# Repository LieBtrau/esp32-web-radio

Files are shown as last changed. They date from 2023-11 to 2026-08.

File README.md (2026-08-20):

# Description

<td>
<table>
  <tr>
    <td>
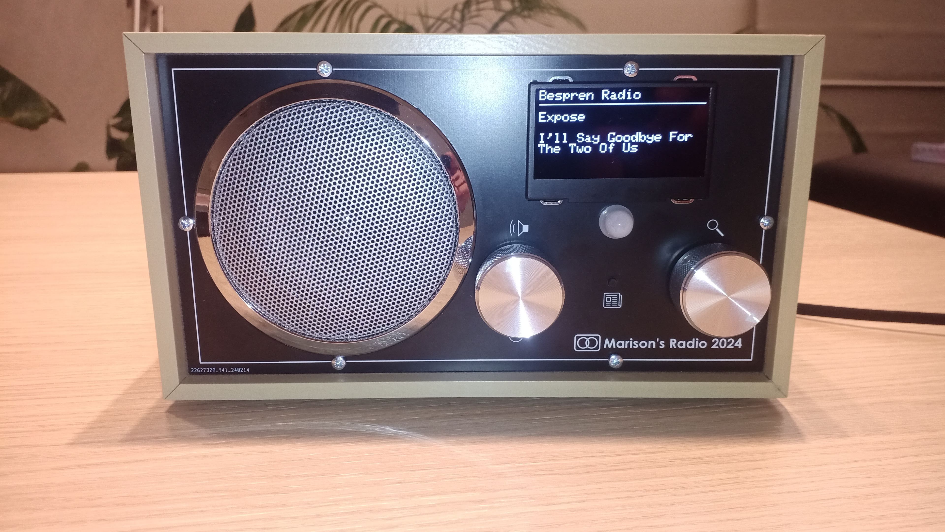
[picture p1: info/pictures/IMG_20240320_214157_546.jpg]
      
    </td>
    <td>
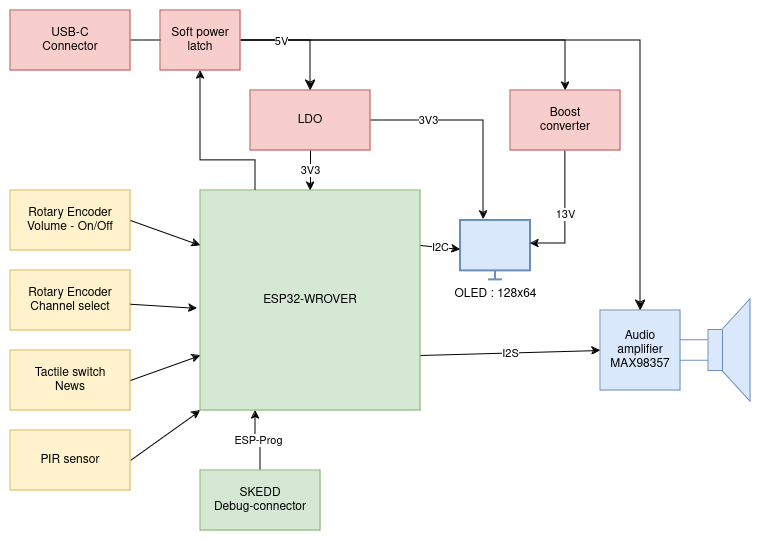
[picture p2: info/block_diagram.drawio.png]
      
    </td>
  </tr>
</table>

# Hardware version 1.0
* [Release binaries](https://github.com/LieBtrau/esp32-web-radio/releases/tag/hw_1.0.0) (gerber data, BoM, PDF schematics, PDF PCB assembly drawing)
* Online Altium viewer (schematic, PCB, 3D view, Draftsman drawing, BoM):
  * [Logic board](https://365.altium.com/files/4109E801-90D9-4754-8810-C3B9F4649D15)
  * [Front panel](https://365.altium.com/files/9F6788B9-9D0B-400C-A80F-A1CFE65F462F)
  * [Power entry module](https://365.altium.com/files/06756B94-5B1C-4D01-91C6-53AC24E7E911)
* Test reports
  * [Logic board](./hardware/testReports/TR_web-radio_1.0.0.md)
  * [Front panel](./hardware/testReports/TR_front-panel_1.0.0.md)
  * [Power entry module](./hardware/testReports/TR_power-entry_1.0.0.md)

# Hardware version 1.1
The hardware version 1.0 is working fine after patching. Ordering new hardware (i.e. this version 1.1) is expensive, wasteful, and time-consuming.

* Release binaries : will not be created
* Online Altium viewer (schematic, PCB, 3D view, Draftsman drawing, BoM)
  * [Logic board](https://365.altium.com/files/9CB82595-BE36-474F-A76E-B6EA8003FF0C)
  * Front panel : will not be created, changes from previous version are minor
  * Power entry module : will not be created, changes from previous version are minor

# Issues
* Power button needs to be pushed for more than 3 s to turn the unit on.  A power latch would be helpful here.
* When no wifi network is found, the screen remains black leaving the user without a clue.  The screen could show a helpful message.
* The unit goes into a temporary reboot loop during some songs until the start of the next song.  It might have something to do with illegal characters being shown on the display or simply a song text that is too long and causes buffer overruns.  To be investigated.
* The original rotary encoder library worked better.  The current one sometimes misses steps.

# Why web radio instead of DAB+?
* DAB+ is limited to local radio stations. Web radio gives access to radio stations from all over the world.
* DAB+ reception quality is not great indoors. The radio must be located near a window and the antenna must be fully extended.
* Sound quality won't probably be worse than DAB+. I'm using a cheap speaker anyway.
* DAB+ is free, but in most places, a Wi-Fi connection is available anyway. The data consumption is low (about 30 MB per hour for a low-quality 64kbps).
* DAB+ receiver modules are not widely available. The probably aren't cheap either.

I think DAB+ has its niche in car radios, but not in home radios.

----
The original repository can be found [here](https://github.com/LieBtrau/esp32-web-radio).

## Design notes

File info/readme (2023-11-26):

ESP8266 : https://hackaday.io/project/11570-wifi-webradio-on-esp8266-or-esp32
https://hackaday.io/project/174041-bonnaroo-jukebox-time-capsule
https://hackaday.io/project/168354-esp32-based-internet-radio-and-bluetooth-speaker

Components:
* VS1053 module (all stations): 
	(https://www.aliexpress.com/item/32354143509.html)
	https://www.aliexpress.com/item/32956293891.html
	https://www.banggood.com/VS1053-MP3-Module-Development-Board-On-Board-Recording-Function-p-1244003.html
* I2S decoder (only mp3 stations): TECNOIOT 2pcs PCM5102 Decoder GY-PCM5102 I2S Interface Format Player Digital Audio PCM5102A
* Audio amplifier:
	https://www.banggood.com/PAM8403-2-Channel-USB-Power-Audio-Amplifier-Module-Board-3Wx2-Volume-Control-p-1068215.html
* audio transformer : from output of mp3 decoder to input of audio amplifier (https://youtu.be/4bm22sN5hWE?t=117)
* ESP32
	watch out for width, so that it still fits a breadboard: 
	NodeMCU-32S
		KS0413 keyestudio ESP32 Core Board (Spiess) platformio : NodeMCU-32S
			http://wiki.ai-thinker.com/esp32/boards/nodemcu_32s
		https://www.aliexpress.com/item/32899558932.html
		https://www.aliexpress.com/item/32998131047.html
		https://wiki.keyestudio.com/KS0413_keyestudio_ESP32_Core_Board
	Wemos LOLIN32 Lite (obsolete, platformio = lolin32)
		https://www.aliexpress.com/item/33009124491.html -> lolin32, https://draeger-it.blog/microcontroller-esp32-lolin32/?cn-reloaded=1
		https://www.aliexpress.com/item/4000340140634.html
		https://www.youtube.com/watch?v=a9f9vHjQSfQ
	wemos D1 mini
		https://www.aliexpress.com/item/4000232057013.html 
		https://www.aliexpress.com/item/32816065152.html 
* ESP32 debugger/programmer
	https://de.aliexpress.com/item/33022365662.html
	https://www.youtube.com/watch?v=psMqilqlrRQ&list=PL3XBzmAj53RnZPeWe799F-uoXERBldhn9&index=40
	https://www.youtube.com/watch?v=0poh_2rBq7E&list=PL3XBzmAj53RnZPeWe799F-uoXERBldhn9&index=38
	SSL: https://www.youtube.com/watch?v=Wm1xKj4bKsY&list=PL3XBzmAj53RnZPeWe799F-uoXERBldhn9&index=33
Source:
* https://github.com/karawin/Ka-Radio32 (simple rotary encoder or android app for control)
* https://github.com/Edzelf/ESP32-Radio (nextion display for control)
* https://github.com/MrBuddyCasino/ESP32_MP3_Decoder (with bluetooth audio output)

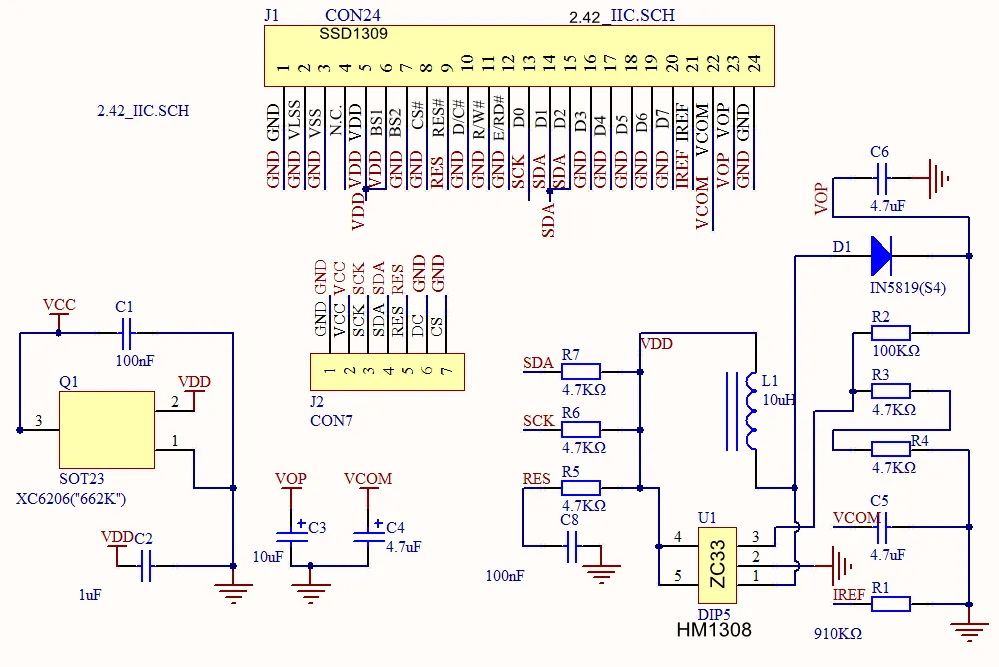
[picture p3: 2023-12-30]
hardware/OLED_pinout_I2C.png

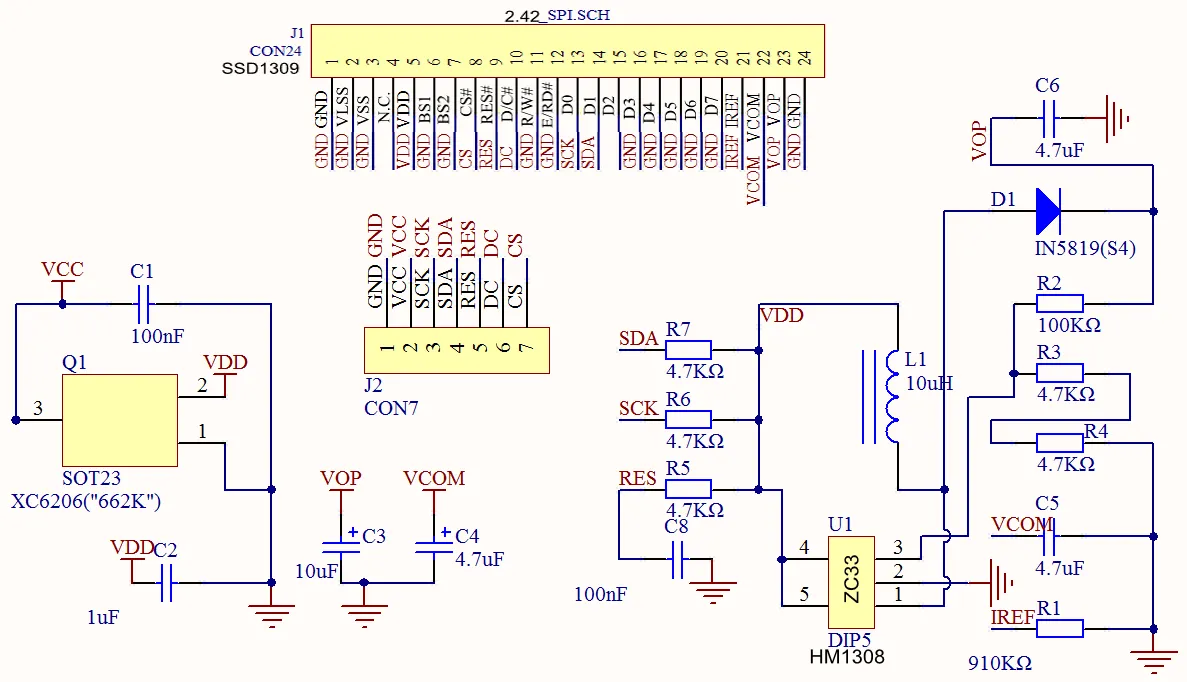
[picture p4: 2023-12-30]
hardware/OLED_pinout_SPI.png

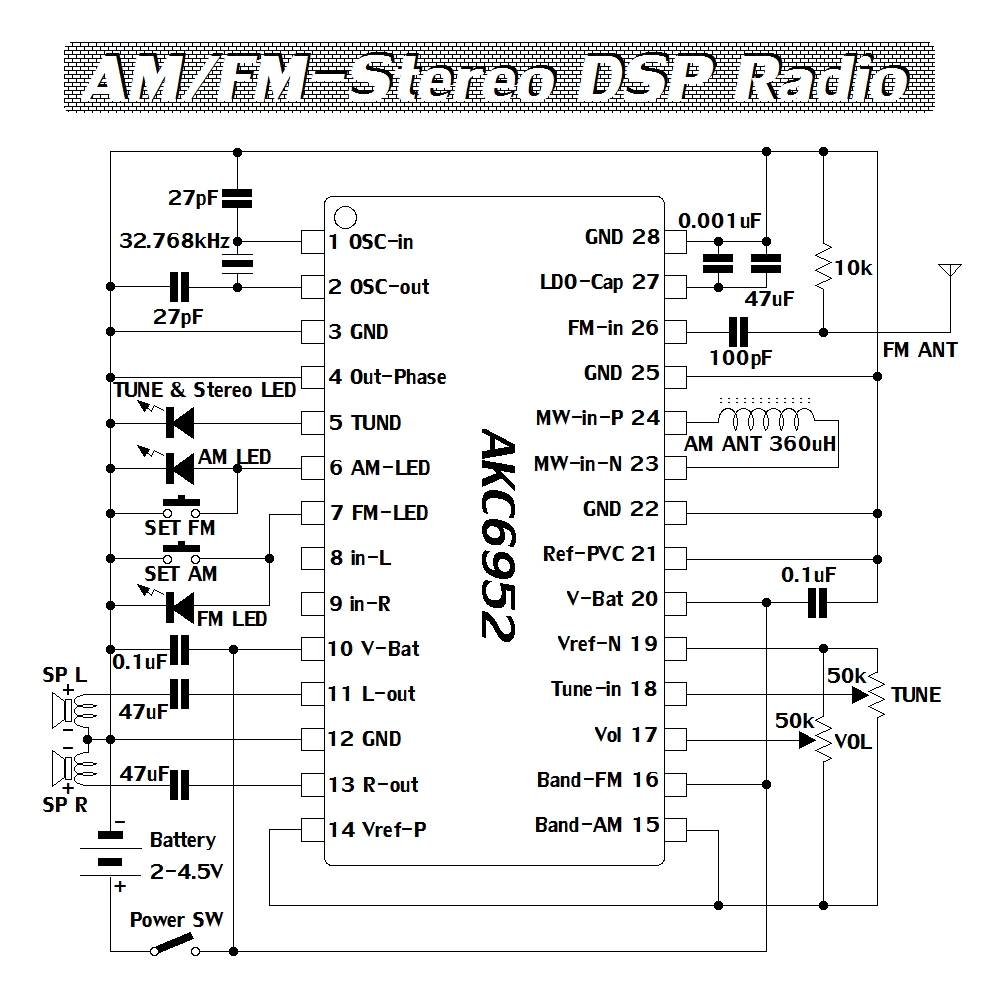
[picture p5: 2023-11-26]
hardware/akc6952_circuit.jpg

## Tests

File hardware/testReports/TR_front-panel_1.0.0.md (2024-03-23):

# Equipment

| Equipment | Description | Serial Number | Date of last calibration |
|---|---|---|---|

# Test Incident Reports

| Test | Incident | Proposed Solution | Status |
|---|---|---|---|
| TIR1 | Tight fit for the speaker in the back of the front panel | Increase holesize by 0.5mm | Open |
| TIR2 | PIR sensor sits at a 45° angle | Rotate footprint so that default orientation shows horizontal window | Open |
| TIR3 | Slots for the OLED screen are too visible| Make slots narrower and don't plate them | Open |
| TIR4 | News button is hard to see | Draw a ring in silkscreen around the hole for the switch  | Open |
| TIR5 | It's not clear when power is on | Add a LED to the front panel | Open |

# Test Results
| Action | Expected Result | Observed result | Status |
|---|---|---|---|

# Test Result Details

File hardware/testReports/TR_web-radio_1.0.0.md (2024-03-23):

# Equipment

| Equipment | Description | Serial Number | Date of last calibration |
|---|---|---|---|
| Multimeter | Mastech M92 | 20011206033 | - |
| Oscilloscope | Siglent SDS2354X HD  | SDS2HBAQ6R0257| TBD |
| Power Supply | Siglent SPD3303C | SPD3EEEC6R0513| TBD |

# Test Incident Reports
| Test | Incident | Proposed Solution | Status |
|---|---|---|---|
| TIR1 | ESP32-WROVER-E-N16R8 fails to flash at 460800baud | See TIR3 | ✅ |
| TIR2 | J1 is not labeled | Add polarity of J1 to silkscreen | ✅ |
| TIR3 | UART.TX doesn't work above 115200baud | Remove C20 | ✅ |
| TIR4 | Noise on 5V line, caused by current peaks | * Power for U3.7&8: Add a zero-ohm link from 3V3 and a 0ohm resistor to 5V<br/>* Replace L1 by an inductor with lower Rdc | ✅ |
| TIR5 | OLED can not be initialized | Change I²C-pull-ups R25 & R26 from 10K to 1K, better use 3.3k | ✅ |
| TIR6 | Rising edge on PROG./RST is too early | * Add supervisor that releases reset when VLED is present<br/>* Add disconnect on booster so that it only gets power once 3V3 is high enough.  | ✅  |
| TIR7 | Rotary encoder doesn't fit | Change footprint : move the two slots 0.3mm further away from the center | ✅ |
| TIR8 | UVLO of U1 is not used | This will be handled by a disconnect circuit, see TIR6. | ✅ |  
| TIR9 | Pushing a button is not always recognized.  Logic low level is too high. | Replace R34, R35, R36, R37 and R40 by 1K<br/>Replace C31, C32, C33, C34 and C36 by 100nF | ✅ |
| TIR10| FFC doesn't go straight into the connector | Shift J2 1mm to the left and lock position in the layout. | ✅ |
| TIR11 | No termination on high speed lines | Add series termination on SPI/I²C lines | ✅ |
| TIR12 | SW1 needs to be pushed for several seconds until the radio turns on. | Initialize the display as soon as possible after powerup to notify that the unit is powered.</br>The built-in ULP might be used to latch the power on.  | Open |

# Test Results
## PBA assembly remarks
| Action | Expected Result | Observed result | Status |
|---|---|---|---|
| Silkscreen on PCB | Polarities are labeled | * J1 is not labeled<br/>* during debug I accidentally put power on the audio output. | TIR2 |
| rotary encoder | easy fit | A hard push is needed to fit these | TIR7 |

## Power & reset
| Action | Expected Result | Observed result | Status |
|---|---|---|---|
| Soft-start of power supply | ms-delay | 1V/ms rising edge<br/>It's important to have reverse current protection (with a series diode.  Q4 doesn't provide reverse current protection).  So that a dropping input voltage, due to high source resistance, doesn't discharge the elcos.  Otherwise a non-monotonous rising edge might occur. | ✅ |
| 5V on C9, without ESP Prog connected | 0V | 0V | ✅ |
| Noise on 5V line |  | 100mVpp | TIR4 |
| 5V on C9, with ESP Prog connected | 5V | 5.01V | ✅ |
| 3.3V on C13, with ESP Prog connected | 3V3 | 3.30V | ✅ |
| Noise on 3.3V on C13 |  | 10mVpp | ✅ <br/>Good news, the ESP32 filtering works perfectly! |
| Noise on ESP32 power C24 | | 12mVpp | ✅ |
| VLED on C6, with ESP Prog connected | 13V | 12.89V | ✅ (ignoring tolerances for now)|
| Reset rising edge | VDD must be stable 50µs before RST signal comes high  | Reset rises too fast. | TIR6 |

## Other
| Action | Expected Result | Observed result | Status |
|---|---|---|---|
| Uploading code to ESP32 | flashing works | * flashing ESP32-WROVER-E-N16R8 using default upload speed (460800baud) fails <br/>* Code upload at 115200 works | TIR1 |
| Checking UART.RX | switches between 3V3 and 0.5V | follows cathode of D8 | ✅ |
| Checking UART.TX | switches between 5V and 0V | * switches between 0.5V and 3V3<br/>* ESP-Prog UART is always 3V3, no matter the output voltage setting of the ESP-Prog<br/>* The ESP32-WROVER has an internal 499ohm resistor on its TX-line, so don't choose the pull-ups a too small value because you'll end up above the Vil of the ESP-Prog. | TIR3 |
| Checking audio output | playing sound | sound plays, but noise is just as loud as the music | TIR4 |
| OLED | shows text | Can not be initialized because SDA=0 (it is 1.5VDC) | TIR5 |
| Button debouncing | no bouncing | When switch is pushed, voltage on IO-line is 0.73V which is too high<br/>The 10K series resistors in the debouncing circuit are too large.  They form a resistor divider with the pull-up resistor inside the MCU. | TIR9 |

# Test Result Details

## TIR4 : Finding out where 5V noise comes from
The noise starts after the ESP32 has booted.

* Pulling /ENABLE low by soldering a wire to GND to avoid ground loops caused by the ESP-Prog.  No effect.
* Disabling U1 has no effect on the noise.  That was to be expected, because it's always powered.
* Measuring noise on C8 : 55mVpp.  So the noise is not coming from the lab power supply.  It's our circuit that's causing the noise.
* Measuring noise on C13 (3V3) : 10mVpp.  So the noise is not coming from the 3V3 line either.
* I accidentally put power on the audio output.  That may have broken the audio amplifier.
* WS and BCLK are switching even when no sound is playing.  SD remains low when no sound is playing. 
* Diode check reveals that U3.9 is short-circuited to +5V.
* To prevent this from happening again, a [transmission gate](https://github.com/LieBtrau/electronics-design-data/tree/master/circuits/transmission_gate) circuit can be added in series with L3 or L4.  This will prevent the audio amplifier from being powered when the ESP32 is not powered.

* Wifi current peaks : 130mA, 5ms wide, every 103ms.
  * The impedance of the power supply is too high.  Currently it's almost 1ohm.  We don't control this impedance.  If a cheap USB-cable is used, this impedance can get even worse.
  * These slow high current peaks can not be filtered out by increasing the capacitors.  At least 10000uF would be needed to filter out these peaks.  This is not feasible.
  * L1 has an Rdc of 730mOhm at 1A, that's too high to be put in series with the power supply of the ESP32.  
* Golden rule : don't power IC's from an unregulated power supply.  The cheapest fix is to power U3 (MAX98357) from 3V3 instead of from 5V.

## TIR5 : OLED can not be initialized
### Chinese devboard with OLED.
The OLED screen works fine on the chinese devkit.  It has an RC on the reset line.  It takes about 50ms for the reset line to reach 3V3.  The 3V3 of the NodeMCU32S falls down to 1.5V during bootup of the board.  The 3V3 of the NodeMCU32s isn't great.  It suffers hard (drops down to 1.68V) due to current spikes of WiFi.  Still, the OLED works here.

Measuring power on sequence : VLED first, then +3V3 and PROG./RST as the last.  This is wrong.  VLED should be the last to power up.  The OLED-screen doesn't seem to care.

### ESP32-web radio
Measuring +3V3, PROG./RST and VLED shows the following power-up sequence: VLED first, then +3V3 and PROG./RST as the last.  This is wrong.  VLED should be the last to power up.

U1 is a boost converter, which has not output disconnect.  The minimum output voltage is the input voltage minus a diode drop.  A PMOS in series with the output or input could be used to prevent the OLED from being powered when the ESP32 is not powered.

1. Pull-up resistors on I²C are 10K, which is too high.  These (R25 & R26) have been replaced by 1K.
2. IO15 is a strapping pin.  It should be pulled high.  It's currently pulled low by R17.  It would be better to choose another GPIO-pin for /CS.

Process of replacing circuitry on the Chinese devkit with the circuitry of the ESP32-web radio:
* Use VLED instead of booster U1 to power the OLED : ✅
* Replace R6 914K by 1M : ✅
* Internal reset of the OLED-screen by PROG./RST : ✅
* VCOMH too much capacitive load?  SSD1309 datasheet recommends 2.2µF.  Solder 10µF/50V in parallel to C5 on the chinese devkit.  ✅

The problem can not be fixed on this unit of ESP32-web radio.  Let's take the second unit and do the following modifications:
* cut the trace /CS loose from the ESP32.  It's a strapping pin.
* Replace R25 and R26 by 1K.
result : ✅

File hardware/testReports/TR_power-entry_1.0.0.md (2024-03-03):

# Equipment

| Equipment | Description | Serial Number | Date of last calibration |
|---|---|---|---|
| Multimeter | Mastech M92 | 20011206033 | - |
| Power Supply | Siglent SPD3303C | SPD3EEEC6R0513 | TBD |

# Test Incident Reports

| Test | Incident | Proposed Solution | Status |
|---|---|---|---|
| TIR1 | Mounting holes are too small | Increase hole size to ⌀3.2mm | Open |
| TIR2 | The two slots are too wide | * decrease slot width by 0.1mm<br/>* lengthen studs to 1.6mm | Open |
| TIR3 | Silkscreen is covered by the back panel | * Decrease font size of the silkscreen text "Power Input" so that it becomes readable <br/>* The current board design can be used, but it will look nicer when mounted with the silkscreen pointing inwards (not visible from the outside of the housing) | Open |
| TIR4 | Polarity of the power input | * Print the polarity of the wire-to-board connector on this PCB<br/>* On current protos, polarity can be marked with a permanent marker. | Open |
| TIR5 | Annular ring of the slots quite narrow | * Increase annular ring width to the same as that of the slot for the USB-C connector | Open |
| TIR6 | Power entry module is green, while back panel is silver colored | Remove soldermask on the outward pointing side and put text in green soldermask. | Open |

# Test Results
| Action | Expected Result | Observed result | Status |
|---|---|---|---|
| Mechanical fit unit in back panel | fits | mounting holes are too small | TIR1 |
| Mechanical fit of the two PCBs | fits | * The two slots are too wide<br/>* The two studs are 1mm long, which is too short. | TIR2 | Open |
| Silkscreen is legible | legible | silkscreen is covered by the back panel | TIR3 |
| Polarity of the power input | correct | it would be helpful to print the polarity of the wire-to-board connector on this PCB. | TIR4 |
| Solder connection between PCBs | sturdy connection | Annular ring of the slots quite narrow | TIR5 |
| USB-C powering | 5V on wire-to-board connector | 5V on wire-to-board connector | ✅ |
| Color matching of power entry to back panel| color matches | power entry module is green, while back panel is silver colored. | TIR6 |

# Test Result Details

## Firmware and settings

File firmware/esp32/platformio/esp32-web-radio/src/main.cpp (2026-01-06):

/**
 * @file main.cpp
 *
 * @author Christoph Tack (you@domain.com)
 * @brief
 * @version 0.1
 * @date 2023-12-02
 *
 * @copyright Copyright (c) 2023
 *
 *
 */
#include "Arduino.h"
#include "WiFi.h"
#include "wifi_credentials.h"
#include <WiFiMulti.h>
#include "StreamDB.h"
#include "RotaryEncoder.h"
#include "pins.h"
#include "Music.h"
#include <Adafruit_SSD1305.h>
#include "OLED_Renderer.h"
#include "ChannelMenu.h"
#include "Bounce2.h"
#include "esp_log.h"

static const uint8_t SSD1305_ADDR = 0x3C;
static const char *STREAMS_FILE = "/streams.json";
static const char *NEWS_STREAM = "VRT NWS";
static const int DEFAULT_SCREEN_TIMEOUT = 240000;
static const int VOLUME_SCREEN_TIMEOUT = 2000;
static const int CHANNEL_SCREEN_TIMEOUT = 5000;
static const int PIR_TIMEOUT = 900000; // 15 minutes
static const char *TAG = "Main";

void showstreamtitle(const String &artist, const String &song_title); // non-static, must be visible to Music.cpp
static void onChannelSelected(const String &name);
static void radio_off();

static Music musicPlayer;
static WiFiMulti wifiMulti;
static StreamDB streamDB;
static RotaryEncoder volumeKnob(PIN_ENCVOL_S1, PIN_ENCVOL_S2, PIN_ENCVOL_KEY);
static RotaryEncoder channelKnob(PIN_ENCCH_S1, PIN_ENCCH_S2, PIN_ENCCH_KEY);
static Adafruit_SSD1305 display(128, 64, &Wire, -1);
static OLED_Renderer renderer(display);
static ChannelMenu channelMenu(&renderer, &channelKnob, onChannelSelected);
static AsyncDelay screenTimeout;
static AsyncDelay pirTimeout;
static String last_artist = "", last_song_title = "";
static Bounce newsButton = Bounce();

enum class ScreenActions
{
    SLEEP,
    SHOW_VOLUME,
    SHOW_CHANNEL,
    SHOW_SONG,
    SHOW_NEWS
};

static ScreenActions screen_state = ScreenActions::SLEEP;

enum class MusicActions
{
    NONE,
    PLAY_NEWS,
    PLAY_CHANNEL,
    DEC_VOLUME,
    INC_VOLUME,
};

static MusicActions music_state = MusicActions::NONE;

void show(ScreenActions action)
{
    String selectedChannel;

    switch (action)
    {
    case ScreenActions::SLEEP:
        renderer.clear();
        break;
    case ScreenActions::SHOW_VOLUME:
        screenTimeout.start(VOLUME_SCREEN_TIMEOUT, AsyncDelay::MILLIS);
        if (streamDB.getCurrentStream(selectedChannel))
        {
            renderer.render_volume(musicPlayer.getVolume(), musicPlayer.getMaxValue(), selectedChannel);
        }
        else
        {
            ESP_LOGE(TAG, "No current stream");
            renderer.clear();
        }
        break;
    case ScreenActions::SHOW_CHANNEL:
        screenTimeout.start(CHANNEL_SCREEN_TIMEOUT, AsyncDelay::MILLIS);
        // Menu rendered automatically by channelMenu
        break;
    case ScreenActions::SHOW_SONG:
        screenTimeout.start(DEFAULT_SCREEN_TIMEOUT, AsyncDelay::MILLIS);
        if (streamDB.getCurrentStream(selectedChannel))
        {
            renderer.render_song(selectedChannel, last_artist, last_song_title);
        }
        else
        {
            ESP_LOGE(TAG, "No current stream");
            renderer.clear();
        }
        break;
    case ScreenActions::SHOW_NEWS:
        screenTimeout.start(DEFAULT_SCREEN_TIMEOUT, AsyncDelay::MILLIS);
        renderer.render_song(NEWS_STREAM, "", "");
        break;
    }
    screen_state = action;
}

void music(MusicActions action)
{
    String selectedChannel = "";
    String url = "";
    uint8_t volume = 0;

    switch (action)
    {
    case MusicActions::NONE:
        break;
    case MusicActions::PLAY_NEWS:
        streamDB.setCurrentStream(NEWS_STREAM);
        streamDB.getVolume(NEWS_STREAM, volume);
        streamDB.getStream(NEWS_STREAM, url);
        musicPlayer.startStream(url.c_str(), volume);
        break;
    case MusicActions::PLAY_CHANNEL:
        if (streamDB.getCurrentStream(selectedChannel))
        {
            ESP_LOGI(TAG, "Selected channel: %s", selectedChannel.c_str());
            streamDB.getVolume(selectedChannel, volume);
            streamDB.getStream(selectedChannel, url);
        }
        musicPlayer.startStream(url.c_str(), volume);
        break;
    case MusicActions::DEC_VOLUME:
        musicPlayer.decreaseVolume();
        streamDB.setVolumeCurrentChannel(musicPlayer.getVolume());
        break;
    case MusicActions::INC_VOLUME:
        musicPlayer.increaseVolume();
        streamDB.setVolumeCurrentChannel(musicPlayer.getVolume());
        break;
    }

    music_state = action;
}

void setup()
{
    ESP_LOGI(TAG, "\r\nBuild %s, %s %s\r\n", AUTO_VERSION, __DATE__, __TIME__);
    pinMode(PIN_PWR_EN, OUTPUT);
    digitalWrite(PIN_PWR_EN, HIGH);
    Wire.setPins(PIN_SDA, PIN_SCL);

    if (!renderer.init(display.begin(SSD1305_ADDR, false)))
    {
        ESP_LOGE(TAG, "Unable to initialize OLED");
    }

    volumeKnob.init();
    channelKnob.init();

    if (!SPIFFS.begin(true))
    {
        ESP_LOGE(TAG, "Cannot mount SPIFFS volume...be sure to upload Filesystem Image before uploading the sketch");
        while (1)
            ;
    }
    streamDB.load(STREAMS_FILE);
    for (int i = 0; i < streamDB.size(); i++)
    {
        String name;
        if (streamDB.getName(i, name) && name.compareTo(NEWS_STREAM) != 0)
        // Don't add VRT NWS to the menu, it's a news channel, which only lasts for a few minutes
        {
            channelMenu.addMenuItem(name.c_str());
        }
    }

    WiFi.disconnect();
    WiFi.mode(WIFI_STA);
    for (int i = 0; i < (sizeof(wifiNetworks) / sizeof(wifiNetworks[0])); i++)
    {
        wifiMulti.addAP(wifiNetworks[i][0], wifiNetworks[i][1]);
    }

    uint8_t stat = WL_DISCONNECTED;
    while (stat != WL_CONNECTED)
    {
        stat = wifiMulti.run();
        ESP_LOGI(TAG, "WiFi status: %d\r\n", (int)stat);
        delay(100);
    }
    ESP_LOGI(TAG, "Connected to WiFi network: %s", WiFi.SSID().c_str());
    ESP_LOGI(TAG, "IP address: %s", WiFi.localIP().toString().c_str());

    if (!musicPlayer.init(I2S_BCLK, I2S_LRC, I2S_DOUT))
    {
        ESP_LOGE(TAG, "Error initializing music player");
    }
    musicPlayer.playSpeech("ooh, Geniet van de muziek, Marison", "nl"); // Google TTS
    while (musicPlayer.isPlaying())
    {
        musicPlayer.update();
    }

    String selectedChannel;
    if (!streamDB.getCurrentStream(selectedChannel))
    {
        streamDB.getFirstStream(selectedChannel);
        streamDB.setCurrentStream(selectedChannel);
    }
    ESP_LOGI(TAG, "Resuming stream: %s", selectedChannel.c_str());
    onChannelSelected(selectedChannel.c_str());

    screenTimeout.start(DEFAULT_SCREEN_TIMEOUT, AsyncDelay::MILLIS);
    pirTimeout.start(PIR_TIMEOUT, AsyncDelay::MILLIS);
    newsButton.attach(PIN_NEWS_BTN, INPUT_PULLUP);
    newsButton.interval(5);
}

void loop()
{
    musicPlayer.update(); // play audio
    if (channelMenu.loop())
    {
        // refresh timeout as long as the user is selecting a channel
        show(ScreenActions::SHOW_CHANNEL);
    }

    newsButton.update();
    if (newsButton.fell() && music_state != MusicActions::PLAY_NEWS)
    {
        ESP_LOGI(TAG, "News button pressed");
        music(MusicActions::PLAY_NEWS);
        show(ScreenActions::SHOW_NEWS);
    }
    if (music_state == MusicActions::PLAY_NEWS && !musicPlayer.isPlaying())
    {
        ESP_LOGI(TAG, "News finished");
        streamDB.restoreLastStream();
        last_artist = "";
        last_song_title = "";
        music(MusicActions::PLAY_CHANNEL);
        show(ScreenActions::SHOW_SONG);
    }

    switch (volumeKnob.rotary_encoder_update())
    {
    case RotaryEncoder::TURN_DOWN:
        music(MusicActions::DEC_VOLUME);
        show(ScreenActions::SHOW_VOLUME);
        break;
    case RotaryEncoder::TURN_UP:
        music(MusicActions::INC_VOLUME);
        show(ScreenActions::SHOW_VOLUME);
        break;
    case RotaryEncoder::BUTTON_FELL:
        radio_off();
        break;
    default:
        break;
    }

    if (screenTimeout.isExpired())
    {
        ESP_LOGI(TAG, "Screen timeout");
        screenTimeout.repeat();
        switch (screen_state)
        {
        case ScreenActions::SLEEP:
            break;
        case ScreenActions::SHOW_VOLUME:
        case ScreenActions::SHOW_CHANNEL:
            show(ScreenActions::SHOW_SONG);
            break;
        case ScreenActions::SHOW_SONG:
            break;
        case ScreenActions::SHOW_NEWS:
            break;
        }
    }

    // PIR sensor
    if (digitalRead(PIN_PIR) == HIGH)
    {
        pirTimeout.restart();
    }
    if (pirTimeout.isExpired())
    {
        ESP_LOGI(TAG, "PIR timeout");
        radio_off();
    }
}

/**
 * @brief Callback function for channel selection (push rotary encoder of the channel knob)
 *
 * @param name
 */
static void onChannelSelected(const String &name)
{
    ESP_LOGI(TAG, "Setting channel: %s", name.c_str());
    streamDB.setCurrentStream(name);
    last_artist = "";
    last_song_title = "";
    music(MusicActions::PLAY_CHANNEL);
}

/**
 * @brief Callback function for showing the song title and artist
 *
 * @param artist
 * @param song_title
 */
void showstreamtitle(const String &artist, const String &song_title)
{
    last_artist = artist;
    last_song_title = song_title;
    show(ScreenActions::SHOW_SONG);
}

void radio_off()
{
    show(ScreenActions::SLEEP);
    musicPlayer.stopStream();
    musicPlayer.playSpeech("Goodbye", "en"); // Google TTS
    if ((streamDB.safeSave(STREAMS_FILE)))
    {
        ESP_LOGI(TAG, "Stream database saved");
    }
    else
    {
        ESP_LOGE(TAG, "Error saving stream database");
    }
    SPIFFS.end();
    while (musicPlayer.isPlaying())
    {
        musicPlayer.update();
    }
    ESP_LOGI(TAG, "Going to sleep");
    delay(1000);
    digitalWrite(PIN_PWR_EN, LOW);
    esp_deep_sleep_start();
}

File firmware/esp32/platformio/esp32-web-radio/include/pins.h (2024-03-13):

#pragma once


// Using an enum instead of #define allows the compiler to catch typos and avoids defining the same pin twice.
typedef enum pin_def_t
{
    // Don't use pin 12 for I2C, it's a strapping pin (MTDI), which should be pulled down to set the voltage of VDD_SDIO to 3.3V.
    // https://randomnerdtutorials.com/esp32-pinout-reference-gpios/
    PIN_SCL = 14,
    PIN_SDA = 13,
    
    // I2S
    I2S_DOUT = 5,
    I2S_LRC = 2,
    I2S_BCLK = 4,

    // Encoder for volume
    PIN_ENCVOL_S1 = 21,
    PIN_ENCVOL_S2 = 19,
    PIN_ENCVOL_KEY = 18,

    // Encoder for channel
    PIN_ENCCH_S1 = 34,
    PIN_ENCCH_S2 = 39,
    PIN_ENCCH_KEY = 36,

    // News button
    PIN_NEWS_BTN = 33,

    // Soft power latch enable
    PIN_PWR_EN = 26,

    // PIR sensor
    PIN_PIR = 27
} pin_def_t;

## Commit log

2023-11-25 Add libraries for audio, knob, buttons, and others
2023-11-25 Add TechDoc.ipynb with housing, display, power source, development kit, firmware, libraries, and radio stations.
2023-11-26 Add button read
2023-11-27 pschatzmann final failed test
    [main.cpp]
2023-11-29 Switching between channels works
2023-12-01 disable ADC
2023-12-01 Enable power amplifier
2023-12-02 Add monitor filters and build flags
2023-12-04 Fix audio stream interruption
2023-12-07 Add O-LED documentation
2023-12-08 Print stream urls to debug instead of info
2023-12-08 Add info about ESP32-Lyra kit
2023-12-08 Move pin definitions to another file
2023-12-08 Add rotary encoder
2023-12-09 O-LED Demo application
2023-12-09 Add rotary encoder test
2023-12-09 Adding O-LED text library
2023-12-09 Tests with ArduinoMenu
2023-12-10 LCDMenuLib2 : doesn't work
    [LCDML_control.cpp, LCDdefines.h, main.cpp]
2023-12-23 Updating pin numbers for test with breadboard
2023-12-23 Move pin definistions to other file
2023-12-25 Encoder for volume and channel selection
2023-12-25 Replace encoder by I²S amplifier
2023-12-25 Using other I2C pins
2023-12-26 Add O-LED output
2023-12-26 Working menu on O-LED
2023-12-27 pushing volume button stops stream
2023-12-27 Replace C char* by String
    [ChannelMenu.cpp, StreamDB.cpp, main.cpp]
2023-12-27 Add PIR sensor info
2024-01-02 Trying to avoid corrupting stream file
    [StreamDB.cpp, main.cpp]
2024-01-06 Schematic and BoM ready for review
    [MCU.SchDoc, esp32-web-radio.PrjPcb]
2024-01-06 Add PIR sensor datasheets
2024-01-10 Add class-D output filter
2024-01-11 Class D filter design
2024-01-11 Add remark about supported ESP32 hardware
2024-01-12 Adapt pin numbers for PCB layout.
2024-01-13 Schematic design finished
    [Input.SchDoc, MCU.SchDoc, Main.SchDoc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]
2024-01-13 Renaming OLED connection schematics
2024-01-13 Final class d output filter
2024-01-13 Add git version number
    [Main.SchDoc]
2024-01-13 Add git ids to schematic
    [Main.SchDoc]
2024-01-13 Add git version numbers to git
    [Input.SchDoc, MCU.SchDoc, Main.SchDoc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]
2024-01-27 Adjust pins according to routed PCB
2024-01-27 Correcting for pin 35 which doesn't have internal pull-up
    [pins.h]
2024-01-27 PCB layout finished, ready for checkout
    [Input.SchDoc, MCU.SchDoc, Main.SchDoc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]
2024-01-28 Mirroring pin numbers of female BTB-socket
    [Input.SchDoc, esp32-web-radio.PrjPcb]
2024-01-31 Moving momentary switch to the middle of the distance between the rotary encoders.
2024-02-01 Replace rotary encoder + add knob
2024-02-02 Replacing 20mm high rotary encoders by 15mm high rotary encoders, because the knobs are only 17mm high.
    [Input.SchDoc]
2024-02-03 Improving ESP32 3V3 power supply filter
    [Input.SchDoc, MCU.SchDoc, esp32-web-radio.PrjPcb]
2024-02-03 Correcting variant part placement
    [esp32-web-radio.PrjPcb]
2024-02-03 First version, ready for review
    [esp32-web-radio-front-panel.PrjPcb, front-panel.PcbDoc, front-panel.SchDoc]
2024-02-04 Add settings to create gerber data
    [esp32-web-radio.PrjPcb]
2024-02-04 Add JLCPCB code for rotary encoder Prepare assembly data
    [Input.SchDoc, Output.SchDoc, esp32-web-radio.PrjPcb]
2024-02-04 Correcting column names for JLCPCB BoM
2024-02-04 Adding output jobs
    [esp32-web-radio-front-panel.PrjPcb]
2024-02-06 Cleaning up reference designators Add Output job for gerber generation
    [esp32-web-radio-front-panel.PrjPcb, front-panel.PcbDoc]
2024-02-10 WEB_RAD_PWR ready for review
    [Main.SchDoc, WEB_RAD_PWR.PcbDoc, WEB_RAD_PWR.PrjPcb]
2024-02-10 Replace rectifier diode by a PMOS.
    [Power.SchDoc]
2024-02-10 Replace project revision by board revision and assembly revision
    [Input.SchDoc, MCU.SchDoc, Main.SchDoc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]
2024-02-10 Update version numbering scheme
    [esp32-web-radio-front-panel.PrjPcb, front-panel.PcbDoc, front-panel.SchDoc]
2024-02-10 Correct pcb name in silkscreen
    [front-panel.PcbDoc]
2024-02-13 Adding output job
    [Main.SchDoc, WEB_RAD_PWR.PcbDoc, WEB_RAD_PWR.PrjPcb]
2024-02-14 Adding documentation Updating sheet templates
    [Input.SchDoc, MCU.SchDoc, Main.SchDoc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]
2024-02-14 Updating schematic templates Adding documentation
    [front-panel.SchDoc]
2024-02-14 forgot to commit
    [esp32-web-radio-front-panel.PrjPcb]
2024-02-14 Adding documentation
    [WEB_RAD_PWR.PrjPcb]
2024-03-03 Fail gracefully when no display connected
    [main.cpp]
2024-03-03 Clean up error reporting warnings
    [ChannelMenu.cpp, Music.cpp, StreamDB.cpp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]
2024-03-03 Avoid rebuilding from scratch every time
    [main.cpp]
2024-03-11 Correct pin assignments for encoders
    [main.cpp, pins.h]
2024-03-12 Add soft power latch
2024-03-14 Add remark about power-on behavior
2024-03-18 esp32-web-radio 1.1.0 ready for review
    [Input.SchDoc, MCU.SchDoc, Output.SchDoc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]
2024-03-24 Updating components from library
    [Input.SchDoc, MCU.SchDoc, Main.SchDoc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]
2024-03-24 Import data from 1.1 PCB design
2024-03-24 Adding logic board version 1.1
2024-05-30 Bug fix, initial volume was not set
    [Music.cpp]
2024-05-30 Fix for file storage corruption
    [StreamDB.cpp, main.cpp]
2026-01-04 Replace rotary encoder library
2026-08-20 Listing issues with the current product.
